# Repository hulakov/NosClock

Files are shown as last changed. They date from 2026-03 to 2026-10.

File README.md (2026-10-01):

# NosClock



**NosClock** is a smart 6-digit Nixie tube clock. It combines vintage **[IN-12 Nixie tubes](https://s.click.aliexpress.com/e/_c3cIzvbx)** with modern electronics: an **ESP32-C3** microcontroller, flicker-free high-voltage drivers, a battery-backed real-time clock, and addressable RGB backlighting. It runs on **[ESPHome](https://esphome.io/)**, so you can control it from **[Home Assistant](https://www.home-assistant.io/)** and use it in [automations](#automation-ideas) (air raid alerts, high CO2 warnings, night mode).

> [!CAUTION]
> **HIGH VOLTAGE WARNING**: This clock generates **170V DC** to power the Nixie tubes. It can cause a severe electric shock or injury. **Do not touch the PCB while it is powered.** Always unplug the power before touching, servicing, or modifying the hardware.

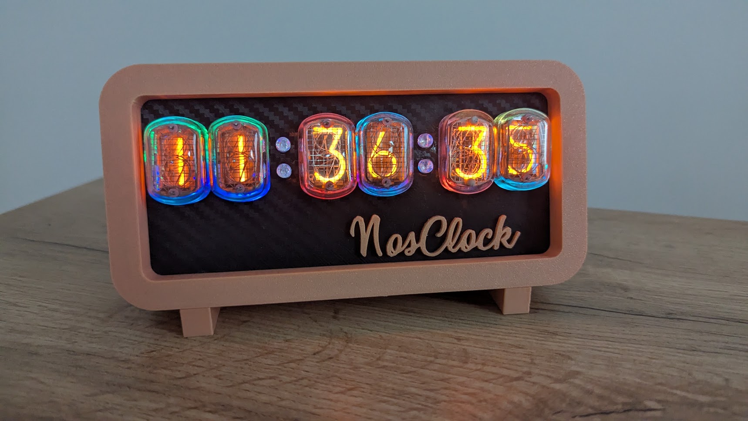
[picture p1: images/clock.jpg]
NosClock Assembly


---

## ✨ Key Features

- **Flicker-Free High-Voltage Shift Register Driving**:
  Uses dedicated high-voltage shift register drivers (**[HV5222PJ](https://ww1.microchip.com/downloads/en/DeviceDoc/20005847A.pdf)**) instead of traditional tube multiplexing. This removes display flicker completely and allows very low tube brightness, perfect for an unobtrusive night mode.

- **Dual RGB LEDs per Digit & RGB Colons**:
  Each Nixie tube is lit from below by **two [SK6812 MINI](https://mouser.com/datasheet/2/737/SK6812MINI_REV02_EN-1501726.pdf) addressable RGB LEDs**, and every colon dot is an RGB LED (4 dots driven by the **[AW9523B](https://www.awinic.com/en/product-detail/AW9523B)** I2C driver). This enables [effects](#home-assistant) like *DigitSync*, *Scanner*, *ScannerDual*, and *ScannerSplit*.

- **Smart Home Integration (Home Assistant via ESPHome)**:
  Control tube brightness, backlight colors, effects, and display power from [Home Assistant](#home-assistant), and use the clock in [automations](#automation-ideas).

- **Dual Time Synchronization (NTP + Battery-Backed RTC)**:
  Time is synchronized via **[NTP](https://en.wikipedia.org/wiki/Network_Time_Protocol)** over Wi-Fi. When offline or after a power loss, the onboard Real-Time Clock (**[DS3231MZ](https://www.analog.com/media/en/technical-documentation/data-sheets/DS3231M.pdf)**) with a CR1220 backup battery keeps the time.

- **Expandable I2C Sensor Interface**:
  A 4-pin I2C connector (`J103`) lets you add sensors such as the **[Sensirion SCD4x](https://sensirion.com/media/documents/48C4B71E/66432D15/Sensirion_CO2_Sensors_SCD4x_Datasheet.pdf)** CO2, temperature, and humidity sensor.

---

## 🔧 Technical Specifications

NosClock uses a custom 2-layer PCB (144 × 60 mm) designed in **[KiCad](https://www.kicad.org/)**, with an enclosure designed in **[Autodesk Fusion 360](https://www.autodesk.com/products/fusion-360)**. The board has an onboard 170V DC boost converter, 32-channel high-voltage shift register drivers, and power regulation from a single 12V DC input.

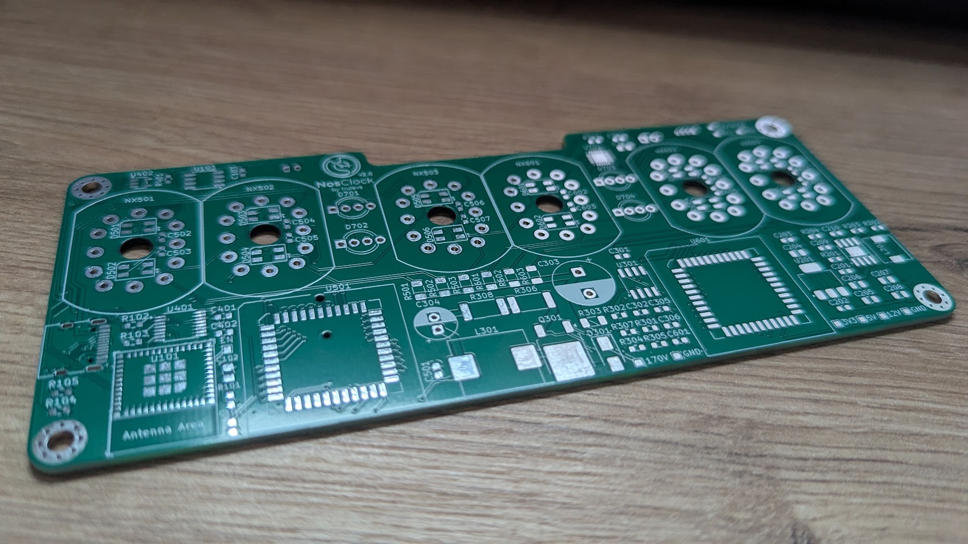
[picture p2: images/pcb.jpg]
NosClock Custom PCB


- **Microcontroller**: Espressif [ESP32-C3-MINI-1](https://www.espressif.com/sites/default/files/documentation/esp32-c3-mini-1_datasheet_en.pdf) module (RISC-V 32-bit single-core CPU, 2.4GHz Wi-Fi 4, Bluetooth 5 LE).
- **Nixie Display Tubes**: 6x **[IN-12B](https://s.click.aliexpress.com/e/_c3cIzvbx)** cold-cathode Nixie tubes.
- **High-Voltage Boost Supply**: Step-up converter built around the [UC3843](https://www.ti.com/lit/ds/symlink/uc3843.pdf) PWM controller and [FQD12N20L](https://www.onsemi.com/pdf/datasheet/fqd12n20l-d.pdf) 200V MOSFET, converting 12V DC to **170V DC** for the tube anodes.
- **Low-Voltage Power Supply**:
  - [MP2307](https://www.monolithicpower.com/en/documentview/productdocument/index/doc_url/%2Fm%2Fp%2Fmp2307_r1.9.pdf) 3A synchronous buck converter: 12V → 5V.
  - [AP7361-33](https://www.diodes.com/assets/Datasheets/AP7361.pdf) 1A LDO regulator: 5V → 3.3V for the ESP32-C3 and logic.
- **Display Driver & Logic**:
  - 2x Microchip [HV5222PJ](https://ww1.microchip.com/downloads/en/DeviceDoc/20005847A.pdf) 32-channel high-voltage shift registers in PLCC-44 sockets.
  - [CD4504](https://www.ti.com/lit/ds/symlink/cd4504b.pdf) CMOS hex level shifter and [SN74LV1T34](https://www.ti.com/lit/ds/symlink/sn74lv1t34.pdf) logic buffer.
- **Timekeeping**: [DS3231MZ](https://www.analog.com/media/en/technical-documentation/data-sheets/DS3231M.pdf) I2C Real-Time Clock with CR1220 battery backup and NTP synchronization.
- **Sensors**:
  - Sensirion [SCD4x / SCD41](https://sensirion.com/media/documents/48C4B71E/66432D15/Sensirion_CO2_Sensors_SCD4x_Datasheet.pdf) CO2, temperature, and humidity sensor (optional, I2C address `0x62`).
  - Dallas [DS18B20](https://datasheets.maximintegrated.com/en/ds/DS18B20.pdf) 1-Wire temperature sensor on GPIO2.
- **RGB Backlight**: 12x [SK6812MINI](https://mouser.com/datasheet/2/737/SK6812MINI_REV02_EN-1501726.pdf) addressable RGB LEDs under the tubes, plus 4x RGB colon LEDs driven by an [AW9523B](https://www.awinic.com/en/product-detail/AW9523B) I2C LED driver.
- **Button**: push button on GPIO21 (toggles the display on/off).
- **Power & Connectivity**:
  - 12V DC input via 2-pin JST-XH connector (`J104`), see [power adapter](#you-will-also-need).
  - USB-C connector (`J101`) for flashing the firmware.

Schematics and PCB layout (KiCad): [`hardware/`](hardware/).

---

## 🛠️ How to Build Your Own NosClock

1. [Order the components](#step-1--order-the-components)
2. [Order the PCB](#step-2--order-the-pcb)
3. [Solder the board](#step-3--solder-the-board) *(guide coming soon)*
4. [3D-print the enclosure](#step-4--3d-print-the-enclosure)
5. [Flash the firmware](#step-5--flash-the-firmware)
6. [Use your clock](#step-6--use-your-clock)

---

### Step 1 — Order the components

Prices are in USD, checked on 2026-09-23. They are item prices only: shipping depends on your country and is not included.

- **Needed**: how many parts go on the board.
- **Order**: how many lots to buy × pieces per lot (sellers often sell only in packs of 2, 5, 10, etc.).
- **Total**: lot price × number of lots.

> **Note:** AliExpress prices change often, and listings can be removed or go out of stock. If a link is broken or a part is unavailable, please [open an issue](https://github.com/hulakov/NosClock/issues) so the list can be updated.

#### Nixie Tubes

| Part | Needed | Order | Lot Price | Total | Link |
|---|---|---|---|---|---|
| IN-12B (NOS) | 6 | 6 × 1 pc | $17.10 | **$102.60** | [buy](https://s.click.aliexpress.com/e/_c3cIzvbx) |

**Nixie tubes total: $102.60**

#### Components

| # | Part | Reference | Needed | Order | Lot Price | Total | Link |
|---|---|---|---|---|---|---|---|
| 1 | ESP32-C3-MINI-1 (N4) | U101 | 1 | 1 × 1 pc | $2.73 | $2.73 | [buy](https://s.click.aliexpress.com/e/_c3xMgjCH) |
| 2 | DS3231MZ SOIC-8 | U103 | 1 | 1 × 2 pcs | $5.22 | $5.22 | [buy](https://s.click.aliexpress.com/e/_c3K8PI7B) |
| 3 | AP7361-33ER-13 SOT-223 | U201 | 1 | 1 × 10 pcs | $6.95 | $6.95 | [buy](https://s.click.aliexpress.com/e/_c3g1RG4p) |
| 4 | MP2307DN-LF-Z SOIC-8 | U202 | 1 | 1 × 5 pcs | $2.02 | $2.02 | [buy](https://s.click.aliexpress.com/e/_c3VXoHP7) |
| 5 | UC3843A SOIC-8 | U301 | 1 | 1 × 10 pcs | $1.62 | $1.62 | [buy](https://s.click.aliexpress.com/e/_c2Jymwnr) |
| 6 | CD4504BPWR TSSOP-16 | U401 | 1 | 1 × 5 pcs | $2.22 | $2.22 | [buy](https://s.click.aliexpress.com/e/_c3nhAJI1) |
| 7 | SN74LV1T34DBVR SOT-23-5 | U402 | 1 | 1 × 10 pcs | $2.27 | $2.27 | [buy](https://s.click.aliexpress.com/e/_c4NBrHu5) |
| 8 | HV5222PJ PLCC-44 | U501, U601 | 2 | 2 × 1 pc | $3.68 | $7.36 | [buy](https://s.click.aliexpress.com/e/_c4b2e8wd) |
| 9 | PLCC-44 SMD socket | U501, U601 | 2 | 1 × 5 pcs | $1.42 | $1.42 | [buy](https://s.click.aliexpress.com/e/_c301jgO5) |
| 10 | AW9523BTQR QFN-24 | U701 | 1 | 1 × 5 pcs | $1.54 | $1.54 | [buy](https://s.click.aliexpress.com/e/_c37MUf2v) |
| 11 | FQD12N20L TO-252 | Q301 | 1 | 1 × 10 pcs | $2.14 | $2.14 | [buy](https://s.click.aliexpress.com/e/_c3Ir5ABP) |
| 12 | ES1J SMA | D301 | 1 | 1 × 50 pcs | $0.38 | $0.38 | [buy](https://s.click.aliexpress.com/e/_c4tBW6Tn) |
| 13 | SK6812MINI 3535 ("BL" variant) | D501–D506, D601–D606 | 12 | 1 × 50 pcs | $5.63 | $5.63 | [buy](https://s.click.aliexpress.com/e/_c4mkH7AZ) |
| 14 | RGB LED 5 mm, 4-pin, common anode (Diffused A) | D701–D704 | 4 | 1 × 20 pcs | $1.36 | $1.36 | [buy](https://s.click.aliexpress.com/e/_c4UarZrj) |
| 15 | Inductor 10 µH, 0630 | L201 | 1 | 1 × 10 pcs | $1.53 | $1.53 | [buy](https://s.click.aliexpress.com/e/_c2QJm98H) |
| 16 | Inductor 100 µH, 1040 (10×10×4 mm) | L301 | 1 | 1 × 5 pcs | $0.98 | $0.98 | [buy](https://s.click.aliexpress.com/e/_c3tJ6fpJ) |
| 17 | USB-C 16P TYPE-C-31-M-12 | J101 | 1 | 1 × 20 pcs | $5.17 | $5.17 | [buy](https://s.click.aliexpress.com/e/_c3UiLAeN) |
| 18 | JST PH 2.0 2-pin (with cable) | J102 | 1 | 1 × 10 sets | $1.18 | $1.18 | [buy](https://s.click.aliexpress.com/e/_c4LT5JFT) |
| 19 | PicoBlade 1.25 mm 4-pin, vertical SMD | J103 | 1 | 1 × 20 pcs | $0.85 | $0.85 | [buy](https://s.click.aliexpress.com/e/_c3mqOP8z) |
| 20 | JST XH 2.54 2-pin (12 V input) | J104 | 1 | 1 × 10 sets | $0.94 | $0.94 | [buy](https://s.click.aliexpress.com/e/_c4mU6YRR) |
| 21 | CR1220 SMD battery holder | BT101 | 1 | 1 × 10 pcs | $1.49 | $1.49 | [buy](https://s.click.aliexpress.com/e/_c4tPLXGV) |
| 22 | Resistor kit 0603 (80 values × 50 pcs): 10R, 330R, 1K, 4.7K ×3, 5.1K ×2, 6.8K, 7.5K, 10K ×2, 30K, 47K, 100K, 150K | R101–R307, R401, R701 | 17 | 1 kit | $5.62 | $5.62 | [buy](https://s.click.aliexpress.com/e/_c2JDtiGD) |
| 23 | Resistor 1206 20K | R501–R503, R601–R603 | 6 | 1 × 100 pcs | $2.25 | $2.25 | [buy](https://s.click.aliexpress.com/e/_c3f9k8vb) |
| 24 | Resistor 1206 680K | R303 | 1 | 1 × 100 pcs | $1.54 | $1.54 | [buy](https://s.click.aliexpress.com/e/_c4BS86Sl) |
| 25 | Resistor 2512 0.25R (R250) | R306, R308 | 2 | 1 × 20 pcs | $0.55 | $0.55 | [buy](https://s.click.aliexpress.com/e/_c42NNZqh) |
| 26 | Capacitor 0603 100nF 50V | 23 positions | 23 | 1 × 200 pcs | $2.10 | $2.10 | [buy](https://s.click.aliexpress.com/e/_c3ccEhY9) |
| 27 | Capacitor kit 0603 (16 values × 20 pcs): 1nF ×2, 10nF, 100pF | C305, C306, C201, C302 | 4 | 1 kit | $2.35 | $2.35 | [buy](https://s.click.aliexpress.com/e/_c3myvgN3) |
| 28 | Capacitor 0603 3.9nF 50V | C210 | 1 | 1 × 100 pcs | $1.50 | $1.50 | [buy](https://s.click.aliexpress.com/e/_c4WOeHQD) |
| 29 | Capacitor 0805 10uF | C204–C206, C702 | 4 | 1 × 100 pcs | $1.22 | $1.22 | [buy](https://s.click.aliexpress.com/e/_c34ZUVWt) |
| 30 | Capacitor 0805 22uF | C207, C208 | 2 | 1 × 100 pcs | $1.75 | $1.75 | [buy](https://s.click.aliexpress.com/e/_c3dSRT0z) |
| 31 | Capacitor 0805 1uF | C102 | 1 | 1 × 100 pcs | $1.03 | $1.03 | [buy](https://s.click.aliexpress.com/e/_c2I0ySdj) |
| 32 | Electrolytic capacitor 4.7uF 400V (D10 mm, P5 mm) | C303 | 1 | 1 × 20 pcs | $0.88 | $0.88 | [buy](https://s.click.aliexpress.com/e/_c3bL90ut) |
| 33 | Electrolytic capacitor 220uF 35V (D6.3 mm, P2.5 mm) | C304 | 1 | 1 × 20 pcs | $3.79 | $3.79 | [buy](https://s.click.aliexpress.com/e/_c3tpnO1T) |

**Components total: $79.58**

#### Grand Total

| | Total |
|---|---|
| Nixie tubes | $102.60 |
| Components | $79.58 |
| **Grand total (excluding shipping)** | **$182.18** |

#### You will also need

- A **12 V DC power adapter** (at least 1 A). Connect it to the JST XH connector from [row 20](#components).
- A **CR1220 coin cell battery** for the [clock backup](#-technical-specifications) (keeps the time when the power is off).
- A **USB-C data cable** for flashing the firmware (a charge-only cable will not work).
- *(Optional)* A **Sensirion SCD41** module with a 4-pin PicoBlade 1.25 mm cable if you want CO2, temperature and humidity readings ([datasheet](https://sensirion.com/media/documents/48C4B71E/66432D15/Sensirion_CO2_Sensors_SCD4x_Datasheet.pdf)). It plugs into `J103`.

---

### Step 2 — Order the PCB

The PCB is ordered as a bare board (no parts soldered). You solder the components from [Step 1](#step-1--order-the-components) yourself ([Step 3](#step-3--solder-the-board)).

1. Download the Gerber file: **[NosClock.zip](hardware/production/NosClock.zip)**. Do not unzip it.
2. Open [jlcpcb.com](https://jlcpcb.com/) and click **Add gerber file**. Upload `NosClock-gerber.zip`.
3. JLCPCB reads most settings from the file. Check that they look like this:

   | Setting | Value |
   |---|---|
   | Base Material | FR-4 |
   | Layers | 2 |
   | Dimensions | 144 × 60 mm (filled in automatically) |
   | PCB Qty | 5 (the minimum order) |
   | PCB Thickness | 1.6 mm |
   | PCB Color | any color you like |
   | Surface Finish | HASL (lead-free) or ENIG. ENIG is flatter and makes the small chips easier to solder |
   | PCB Assembly | **off** |

4. *(Optional, recommended)* Turn on **SMT Stencil**. A stencil makes it much easier to apply solder paste to the small chips.
5. Click **Save to Cart**, then check out and pick a shipping method.

---

### Step 3 — Solder the board

> [!NOTE]
> **A detailed step-by-step soldering guide is coming soon.**

The [interactive BOM](hardware/bom/ibom.html) shows where each part goes on the board. Download the file and open it in your browser.

---

### Step 4 — 3D-print the enclosure

1. Download the STL files from the [`enclosure/`](enclosure/) folder ([online preview](https://a360.co/4aOHyom)).
2. Print them with **PLA** or **PETG**. A 0.2 mm layer height works well.
3. Put the soldered board with the tubes into the enclosure.

---

### Step 5 — Flash the firmware

The clock runs on **[ESPHome](https://esphome.io/)**. The easiest way to flash it is with the **[ESPHome Device Builder](https://esphome.io/guides/getting_started_hassio/)** add-on in [Home Assistant](https://www.home-assistant.io/). You only need a USB cable for the first flash. After that, updates install over Wi-Fi.

#### 5.1 Install ESPHome Device Builder

1. [Open the ESPHome Device Builder add-on in your Home Assistant](https://my.home-assistant.io/redirect/supervisor_addon/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) (or go to **Settings → Add-ons → Add-on Store** and find **ESPHome Device Builder**).
2. Click **Install**, then **Start**, then **Open Web UI**.

#### 5.2 Add the NosClock configuration

1. In ESPHome Device Builder, click **Secrets** (top-right corner) and add these lines with your own values:
   ```yaml
   wifi_ssid: "Your_WiFi_Name"
   wifi_password: "Your_WiFi_Password"
   nosclock_ap_password: "Any_Password_For_Fallback_Hotspot"
   nosclock_api_key: "Your_API_Encryption_Key"
   nosclock_ota_password: "Any_Password_For_Updates"
   ```
   To get `nosclock_api_key`, open the [ESPHome API page](https://esphome.io/components/api.html#configuration-variables). It generates a random key for you. Copy the key and save it somewhere, because you will need it again in [step 5.4](#54-add-the-clock-to-home-assistant).
2. Click **+ New Device** → **Continue** → enter the name `nosclock` → choose **ESP32-C3** → **Skip**.
3. On the new `nosclock` card, click **Edit**. Delete everything in the file and paste the contents of [`esphome/nosclock.yaml`](esphome/nosclock.yaml). Click **Save**.
4. *(Optional)* In the file, change `timezone: "Europe/Kiev"` to [your time zone](https://en.wikipedia.org/wiki/List_of_tz_database_time_zones) and `altitude_compensation: 180m` to your altitude.

#### 5.3 Flash over USB (first time only)

1. On the `nosclock` card, click **⋮ → Install → Manual download**. Wait for the build to finish (the first build takes a few minutes), then choose **Factory format** to download the `.bin` file.
2. Connect the clock to your computer with the USB-C cable.
3. Open [web.esphome.io](https://web.esphome.io) in **Chrome** or **Edge**. Click **Connect** and select the clock's serial port.
4. Click **Install**, select the downloaded `.bin` file, and wait until it finishes.

#### 5.4 Add the clock to Home Assistant

1. Unplug the USB cable and power the clock from the [12 V adapter](#you-will-also-need). It connects to your Wi-Fi.
2. In Home Assistant, go to **[Settings → Devices & services](https://my.home-assistant.io/redirect/integrations/)**. You will see **NosClock** as a discovered device. Click **Configure**.
3. When it asks for the encryption key, paste your `nosclock_api_key` from [step 5.2](#52-add-the-nosclock-configuration).

To install future updates, click **⋮ → Install → Wirelessly** on the `nosclock` card. You do not need the USB cable anymore.

> [!TIP]
> If the clock cannot connect to your Wi-Fi (for example, the password is wrong), it creates its own Wi-Fi network called **NosClock Fallback Hotspot**. Connect to it with your `nosclock_ap_password`. A page opens where you can choose your Wi-Fi network.

<details>
<summary>Advanced: flash with the ESPHome command line instead</summary>

1. [Install ESPHome](https://esphome.io/guides/installing_esphome/): `pip install esphome`
2. Clone [this repository](https://github.com/hulakov/NosClock) and create `esphome/secrets.yaml` with the same lines as in [step 5.2](#52-add-the-nosclock-configuration).
3. Connect the clock via USB-C and run:
   ```bash
   esphome run esphome/nosclock.yaml
   ```
</details>

---

### Step 6 — Use your clock

The clock gets the time from the internet over Wi-Fi. When there is no internet, it keeps time with its built-in battery-backed clock.

#### Button

- **Press**: turns the tubes and the backlight on or off.

#### Home Assistant

Go to **[Settings → Devices & services](https://my.home-assistant.io/redirect/integrations/) → ESPHome → NosClock** to control the clock:

- **Tubes** (light): turn the tubes on or off and set their brightness.
- **Backlight** (light): the color and brightness of the RGB lights under the tubes.
- **Dots** (light): the color and brightness of the colon dots.
- **Display Effect** (select): the backlight effect. The options are `Solid`, `Static`, `DigitSync`, `Scanner`, `ScannerDual`, `ScannerSplit`, and `Cycle`.
- **Sensors**: Temperature. With the [optional SCD41 module](#you-will-also-need) you also get CO2, Ambient Temperature, Ambient Humidity, and **High CO2 Alert** (turns on above 1500 ppm).

You can also open the clock's web page at [http://nosclock.local](http://nosclock.local).

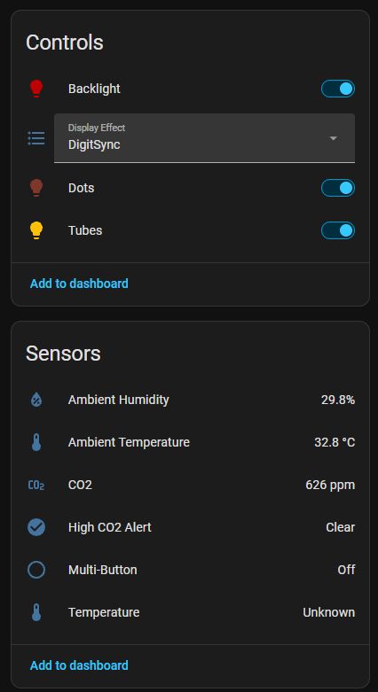
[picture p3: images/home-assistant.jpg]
Home Assistant Integration


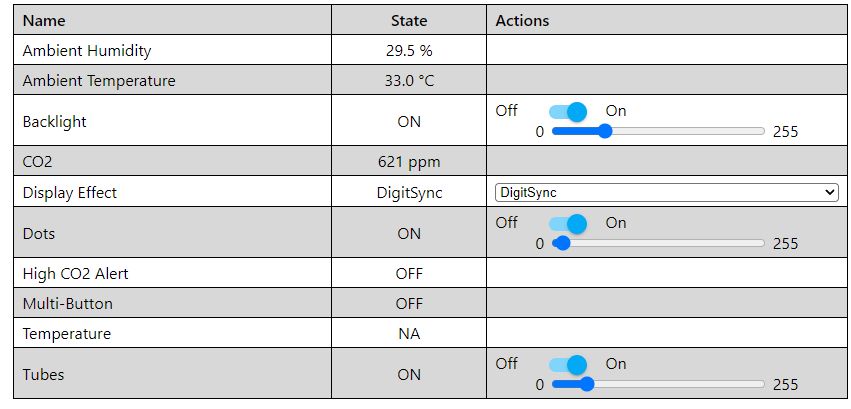
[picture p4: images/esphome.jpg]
ESPHome Controls


#### Automation ideas

- **Air raid alerts (Повітряна тривога)**: install the [NosAlert](https://github.com/hulakov/NosAlert) integration and [create an automation](https://www.home-assistant.io/docs/automation/basics/) that changes the backlight color or effect when an alert starts in your region.
- **Night mode**: lower the tube brightness at night and turn it back up in the morning.
- **High CO2 warning**: flash the backlight red when **High CO2 Alert** turns on.

---

## 💛 Support the Project

If you like NosClock, you can support its development:



---

## 📄 License

This project is licensed under open-source terms. See project files for details.

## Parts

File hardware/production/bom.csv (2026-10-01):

Designator | Footprint | Quantity | Value | LCSC Part #
BT101 | BAT_CH291-1220LF | 1 | Battery_Cell
C101, C103, C202, C203, C209, C301, C401, C402, C501, C502, C503, C504, C505, C506, C507, C601, C602, C603, C604, C605, C606, C607, C701 | 0603 | 23 | 100nF
C102 | 0805 | 1 | 1uF
C201 | 0603 | 1 | 10nF
C204, C205, C206, C702 | 0805 | 4 | 10uF
C207, C208 | 0805 | 2 | 22uF
C210 | 0603 | 1 | 3.9nF
C302 | 0603 | 1 | 100pF
C303 | CP_Radial_D10.0mm_P5.00mm | 1 | 4.7uF 400V
C304 | CP_Radial_D6.3mm_P2.50mm | 1 | 220uF 35V
C305, C306 | 0603 | 2 | 1nF
D301 | D_SMA | 1 | ES1J
D501, D502, D503, D504, D505, D506, D601, D602, D603, D604, D605, D606 | LED_SK6812MINI_PLCC4_3.5x3.5mm_P1.75mm | 12 | SK6812MINI_ALI
D701, D702, D703, D704 | LED_D5.0mm-4_RGB_Wide_Pins | 4 | LED_RAGB
J101 | USB_C_Receptacle_HRO_TYPE-C-31-M-12 | 1 | USB_C_Receptacle_USB2.0_16P
J102 | JST_PH_B2B-PH-K_1x02_P2.00mm_Vertical | 1 | Conn_01x02
J103 | Molex_PicoBlade_53047-0410_1x04_P1.25mm_Vertical | 1 | Conn_01x04
J104 | JST_XH_B2B-XH-A_1x02_P2.50mm_Vertical | 1 | 12V IN
L201 | L_6.3x6.3_H3 | 1 | 10uH 4A
L301 | L_Chilisin_BMRF00101040 | 1 | 100uH
NX501, NX502, NX503, NX601, NX602, NX603 | nixies-us-IN-12 | 6 | IN-12B
Q301 | TO-252-2 | 1 | FQD12N20L
R101, R307 | 0603 | 2 | 10K
R102, R103, R701 | 0603 | 3 | 4.7K
R104, R105 | 0603 | 2 | 5.1K
R201 | 0603 | 1 | 100K
R202 | 0603 | 1 | 30K
R203 | 0603 | 1 | 6.8K
R204 | 0603 | 1 | 7.5K
R301 | 0603 | 1 | 150K
R302 | 0603 | 1 | 10R
R303 | 1206 | 1 | 680K
R304 | 0603 | 1 | 1K
R305 | 0603 | 1 | 47K
R306, R308 | 2512 | 2 | 0.25R
R401 | 0603 | 1 | 330R
R501, R502, R503, R601, R602, R603 | 1206 | 6 | 20K
TP_101 | TestPoint_Pad_1.0x1.0mm | 1 | 170V
TP_102 | TestPoint_Pad_1.0x1.0mm | 1 | EN
TP_103 | TestPoint_Pad_1.0x1.0mm | 1 | 5V
TP_104 | TestPoint_Pad_1.0x1.0mm | 1 | 3V3
TP_105 | TestPoint_Pad_1.0x1.0mm | 1 | SDA
TP_106 | TestPoint_Pad_1.0x1.0mm | 1 | 12V
TP_107 | TestPoint_Pad_1.0x1.0mm | 1 | SCL/BOOT
TP_108, TP_109, TP_110 | TestPoint_Pad_1.0x1.0mm | 3 | GND
U101 | ESP32-C3-MINI-1 | 1 | ESP32-C3-MINI-1
U103 | SOIC-8_3.9x4.9mm_P1.27mm | 1 | DS3231MZ
U201 | SOT-223-3_TabPin2 | 1 | AP7361-33ER-13
U202 | SOIC-8-1EP_3.9x4.9mm_P1.27mm_EP2.29x3mm_ThermalVias | 1 | MP2307DN-LF-Z
U301 | SOIC-8_3.9x4.9mm_P1.27mm | 1 | UC3843_SOIC8
U401 | TSSOP-16_4.4x5mm_P0.65mm | 1 | CD4504
U402 | SOT-23-5 | 1 | SN74LV1T34DBV
U501, U601 | PLCC-44_SMD-Socket | 2 | HV5222PJ
U701 | QFN-24-1EP_4x4mm_P0.5mm_EP2.7x2.7mm | 1 | AW9523B

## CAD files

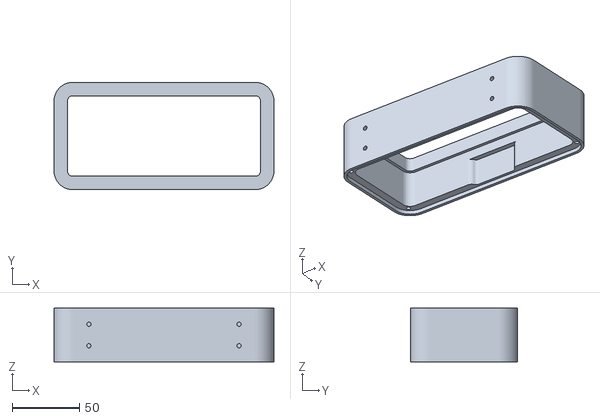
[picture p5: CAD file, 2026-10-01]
enclosure/Main Body.stl
164.0 x 80.0 x 40.0

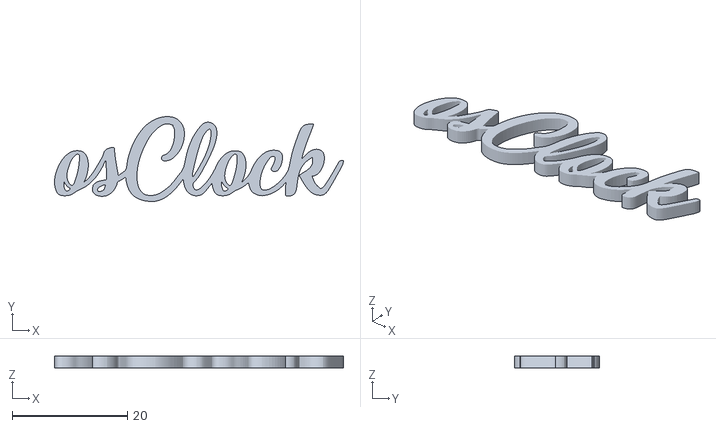
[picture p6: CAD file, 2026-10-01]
enclosure/osClock.stl
50.2 x 14.7 x 2.00

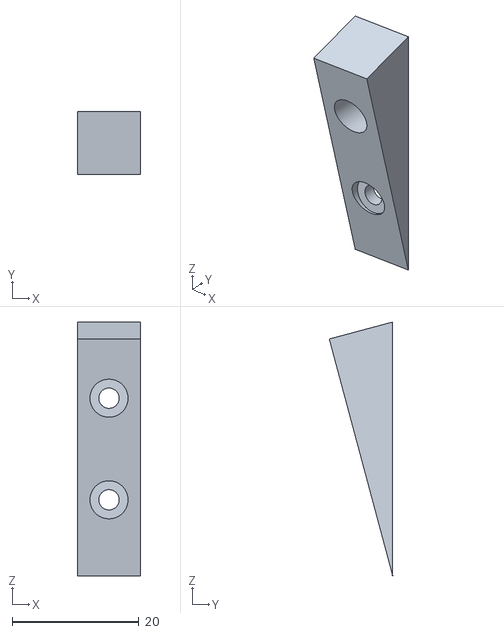
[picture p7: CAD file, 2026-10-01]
enclosure/Leg1.stl
10.0 x 10.0 x 40.0

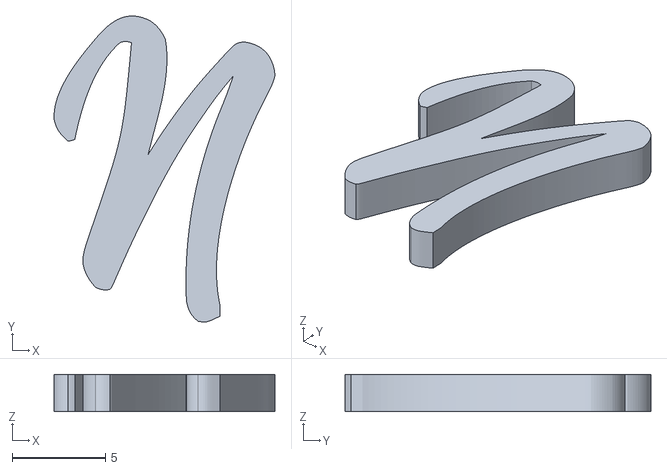
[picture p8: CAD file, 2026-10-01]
enclosure/N.stl
11.8 x 16.4 x 2.00

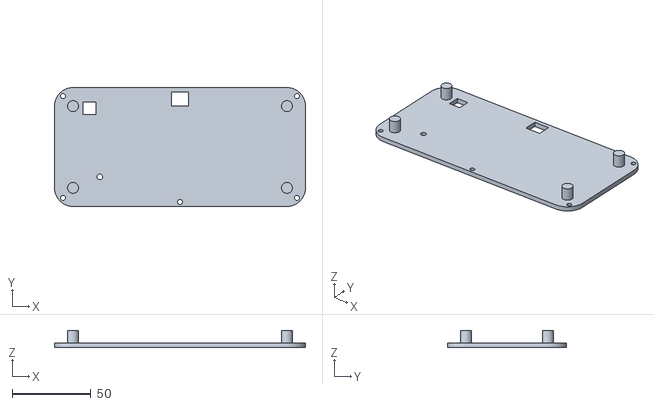
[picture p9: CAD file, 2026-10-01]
enclosure/Back Cover.stl
159.6 x 75.6 x 11.1

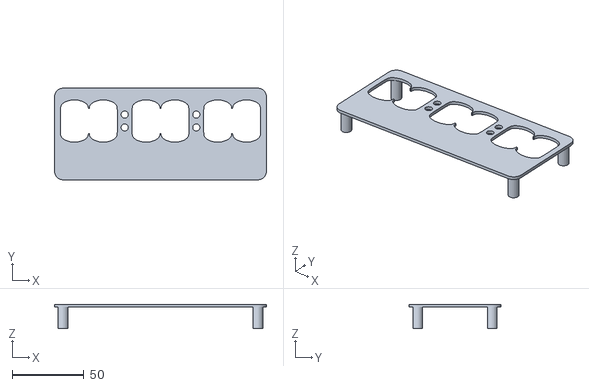
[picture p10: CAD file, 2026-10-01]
enclosure/Front Panel.stl
148.0 x 64.0 x 17.0

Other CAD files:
enclosure/Leg2.stl
enclosure/NosClock.f3z

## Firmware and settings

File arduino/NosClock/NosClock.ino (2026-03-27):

#include "nos_time.h"
#include "nos_clock_impl.h"

#include <time.h>
#include <sys/time.h>
#include <OneWire.h>
#include <DallasTemperature.h>

#include "config.h" 


NosClockImpl clock_logic;
NosTime time_logic;
OneWire oneWire(2);
DallasTemperature sensors(&oneWire);


void setup() {
    Serial.begin(115200);
    
    Wire.begin(8, 9);    
    sensors.begin();
    
    time_logic.setup();
    clock_logic.setup();
    

}

void serial_loop() 
{
    if (Serial.available() == 0) {
        return;
    }

    String input = Serial.readStringUntil('\n');
    input.trim();
    
    if (input.length() == 0) 
    {
        return;
    }

    // List of primary colors for cycling
    static const CRGB colors[] = {
        CRGB::Red, CRGB::Green, CRGB::Blue, 
        CRGB::Yellow, CRGB::Cyan, CRGB::Magenta, CRGB::White
    };
    static const int num_colors = sizeof(colors) / sizeof(colors[0]);
    static int current_color_idx = 2; // Default to Blue

    char cmd = input[0];

    // Command 'e': Toggle Enabled
    if (cmd == 'e') {
        static bool current_enabled = true;
        current_enabled = !current_enabled;
        clock_logic.enable(current_enabled);
        Serial.printf("Clock state toggled: %s\n", current_enabled ? "ENABLED" : "DISABLED");
    }
    // Command 'm': Cycle Effects Mode
    else if (cmd == 'm') {
        int mode = (static_cast<int>(clock_logic.get_effect_mode()) + 1) % static_cast<int>(NosClockEffect::Count);
        
        // Use the currently selected color instead of hardcoded Blue
        clock_logic.set_effect(static_cast<NosClockEffect>(mode), colors[current_color_idx]);
        Serial.printf("Effect mode changed to: %d (Color index: %d)\n", mode, current_color_idx);
    }
    // Command 'c': Cycle Colors
    else if (cmd == 'c') {
        current_color_idx = (current_color_idx + 1) % num_colors;
        
        // Apply new color to the current effect immediately
        NosClockEffect current_mode = clock_logic.get_effect_mode();
        clock_logic.set_effect(current_mode, colors[current_color_idx]);
        
        Serial.printf("Color changed to index: %d\n", current_color_idx);
    }
    // Numerical Input: Set Brightness
    else if (isdigit(cmd)) {
        int brightness_percent = input.toInt();
        if (brightness_percent < 0) brightness_percent = 0;
        if (brightness_percent > 100) brightness_percent = 100;
        
        clock_logic.set_brightness(brightness_percent);
        Serial.printf("Set brightness: %d%%\n", brightness_percent);
    }
}

void loop() {
    serial_loop();

    time_logic.loop();

    // // --- TEMPERATURE LOGIC ---
    // static unsigned long lastTemp = 0;
    // if (millis() - lastTemp > 60000) {
    //     sensors.requestTemperatures();
    //     Serial.printf("NosClock Temp: %.2f C\n", sensors.getTempCByIndex(0));
    //     lastTemp = millis();
    // }
}

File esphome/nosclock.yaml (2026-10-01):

esphome:
  name: nosclock
  friendly_name: NosClock
  on_boot:
    - priority: 600
      then:
        - ds1307.read_time: rtc_time
        - logger.log: "Read RTC time"


esp32:
  board: esp32-c3-devkitm-1
  framework:
    type: esp-idf

external_components:
  - source:
      type: git
      url: https://github.com/hulakov/NosClock
      ref: master
      path: esphome/components
    components: [nosclock]
  # - source:
  #     type: local
  #     path: components

nosclock:
  id: nosclock_controller
  i2c_id: bus_i2c
  time_id: rtc_time
  tubes_light: tubes_light
  backlight_strip: backlight_strip
  tubes_en: tubes_en
  update_interval: 20ms

# Enable logging
logger:

# Enable Home Assistant API
api:
  encryption:
    key: !secret nosclock_api_key

ota:
  - platform: esphome
    password: !secret nosclock_ota_password

wifi:
  ssid: !secret wifi_ssid
  password: !secret wifi_password
  power_save_mode: NONE

  # Enable fallback hotspot (captive portal) in case wifi connection fails
  ap:
    ssid: "NosClock Fallback Hotspot"
    password: !secret nosclock_ap_password

captive_portal:

web_server:
  port: 80


i2c:
  sda:
    number: GPIO8
    ignore_strapping_warning: true
  scl:
    number: GPIO9
    ignore_strapping_warning: true
  id: bus_i2c

time:
  - platform: ds1307
    id: rtc_time
    update_interval: never
  - platform: sntp
    id: sntp_server
    timezone: "Europe/Kiev"
    servers:
      - "pool.ntp.org"
    on_time_sync:
      then:
        - ds1307.write_time:
            id: rtc_time
        - logger.log: "NTP -> RTC Sync Completed"
    update_interval: 1h

one_wire:
  - platform: gpio
    pin:
      number: GPIO2
      ignore_strapping_warning: true

output:
  - platform: ledc
    pin: GPIO10
    id: tubes_en
    frequency: 1000Hz

  - platform: template
    id: virtual_tubes_out
    type: float
    write_action:
      - lambda: ""

light:
  - platform: monochromatic
    name: "Tubes"
    id: tubes_light
    output: virtual_tubes_out
    default_transition_length: 0s
    restore_mode: RESTORE_DEFAULT_ON

  - platform: esp32_rmt_led_strip
    pin: GPIO20
    num_leds: 12
    name: "Backlight"
    id: backlight_strip
    rgb_order: GRB
    chipset: WS2812
    default_transition_length: 0s
    restore_mode: RESTORE_DEFAULT_ON
    gamma_correct: 0.0
    effects:
      # Solid backlight color with dots blinking every second
      - addressable_lambda:
          name: "Solid"
          lambda: ""
      # Completely static backlight and dots without blinking
      - addressable_lambda:
          name: "Static"
          lambda: ""
      # Backlight color synchronized with time digits using a palette (dots blink)
      - addressable_lambda:
          name: "DigitSync"
          lambda: ""
      # Sequential scanner animation travelling across all digits and dots
      - addressable_lambda:
          name: "Scanner"
          lambda: ""
      # Dual scanner animation travelling across pairs of digits and dots
      - addressable_lambda:
          name: "ScannerDual"
          lambda: ""
      # Circular split scanner animation running in a loop across top and bottom LEDs
      - addressable_lambda:
          name: "ScannerSplit"
          lambda: ""
      # Solid backlight with both backlight and dots blinking every second
      - addressable_lambda:
          name: "Cycle"
          lambda: ""


sensor:
  - platform: scd4x
    address: 0x62
    co2:
      name: "CO2"
      id: co2_sensor
      accuracy_decimals: 0
    temperature:
      name: "Ambient Temperature"
      accuracy_decimals: 1
    humidity:
      name: "Ambient Humidity"
      accuracy_decimals: 1
    update_interval: 60s
    automatic_self_calibration: true
    altitude_compensation: 180m

binary_sensor:
  - platform: gpio
    pin:
      number: GPIO21
      mode: INPUT_PULLUP
      inverted: true
    name: "Multi-Button"
    id: clock_button
    on_press:
      - lambda: |-
          nosclock_controller->toggle_clock();

  - platform: template
    name: "High CO2 Alert"
    id: high_co2_alert
    device_class: gas
    lambda: |-
      if (std::isnan(id(co2_sensor).state)) {
        return {}; // Unknown state if sensor is warming up
      }
      if (id(co2_sensor).state >= 1500) {
        return true;  // Threshold exceeded - trigger alert
      }
      if (id(co2_sensor).state <= 1400) {
        return false; // Air quality normal - clear alert
      }
      return id(high_co2_alert).state; // Hysteresis window (1400-1500 ppm) - retain previous state

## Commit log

2026-01-17 initial version
    [NosClock.kicad_pcb, NosClock.kicad_sch]
2026-02-19 Lamps & 3.3v/5v
    [Digit.kicad_sch, Dot.kicad_sch, Dots.kicad_sch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]
2026-02-21 Static version (incomplete)
    [Dots.kicad_sch, LDO.kicad_sch, Lamps.kicad_sch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]
2026-02-23 2/static version
    [Digit.kicad_sch, Dots.kicad_sch, HighSideSwitch.kicad_sch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]
2026-02-27 Finalize schematics
    [HighSideSwitch.kicad_sch, Lamps.kicad_sch, MP2307.kicad_sch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]
2026-02-27 Add logo
    [NosClock.kicad_pcb]
2026-03-27 Arduino firwware
2026-04-13 Lamps tracing
    [Colons.kicad_sch, Lamps.kicad_sch, NosClock.kicad_pcb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]
2026-04-23 almost ready but need to redesign
    [Colons.kicad_sch, Lamps.kicad_sch, MP2307.kicad_sch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]
2026-04-26 connect all
    [NosClock.kicad_pcb, NosClock.kicad_sch]
2026-04-26 update fp
    [NosClock.kicad_pcb]
2026-04-30 finalize v2 tracing
    [NosClock.kicad_pcb]
2026-06-06 bugfixing
    - usb- and usb+ messed up
    - wrong boot label
    [NosClock.kicad_pcb, NosClock.kicad_sch]
2026-06-06 Fix lamps footprints
    [NosClock.kicad_pcb, NosClock.kicad_sch]
2026-10-01 Update readme and add missing files
    [.step, Back Cover.stl, Front Panel.stl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]
2026-10-01 feat(esphome): add calibrated hardware output mapping for backlight and dots
    - Define hardware-specific min and max raw bounds for backlight LEDs and RGB colon dots
    - Map normalized color values to calibrated min..max output range when intensity > 0.1%
2026-10-01 feat(esphome): add slot-machine odometer rolling effect for tubes every 10 min
    - Implement tube digit rolling animation triggered at xx:x9:59 (every 10 minutes)
    - Replace individual time variables with 6-digit array state tracking in NosTubes
    - Switch external_components source in nosclock.yaml to local path for development
    [nos_tubes.cpp, nosclock.yaml]
2026-10-01 refactor(esphome): convert NosController into PollingComponent with native YAML schema
    - Inherit NosController from PollingComponent and handle 20ms updates natively via update()
    - Add i2c_id, time_id, tubes_light, backlight_strip, and tubes_en parameters to nosclock component schema in __init__.py
    - Initialize hardware automatically in setup() and remove manual interval lambda & setup_hardware call from nosclock.yaml
